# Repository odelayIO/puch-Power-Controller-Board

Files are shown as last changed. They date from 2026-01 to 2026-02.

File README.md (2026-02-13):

# puch-Power-Controller-Board

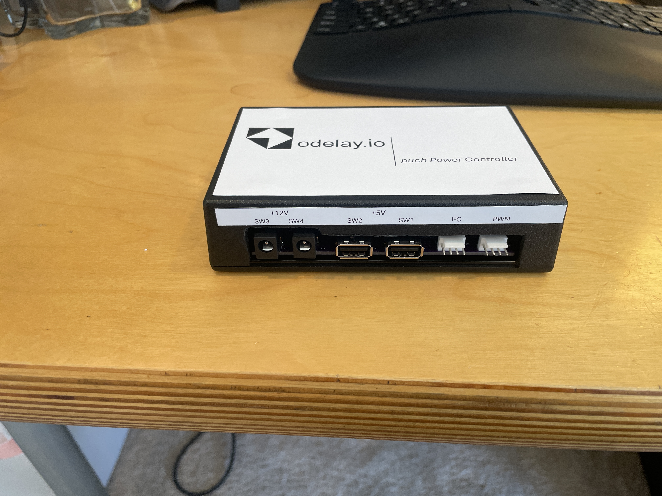
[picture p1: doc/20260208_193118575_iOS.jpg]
20260208_193118575_iOS


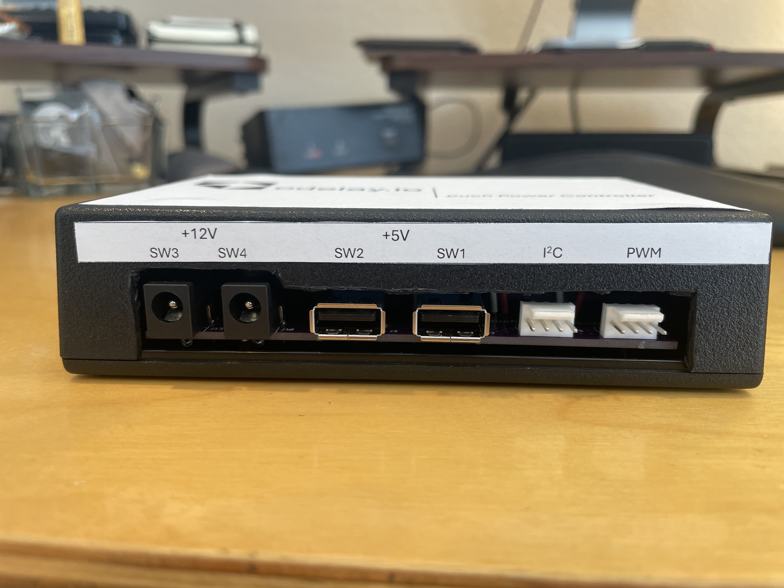
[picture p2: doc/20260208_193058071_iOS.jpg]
20260208_193058071_iOS


## Overview

KiCAD 9.0 board design for the puch Power Controller Board.  This boad has the following features:

- Create a custom PCB to remotely control the power input for KR260, PYNQ-Z1, and both Pluto SDRs
- Single 12VDC power supply will source power to all 4 devices
- Add clean external power to both Pluto SDRs (minimum ripple noise)
- Add PWM fan controlled by the ESP32 micro-controller to adjust fan speed
- Integration to Home Assistant via MQTT device
- Utilize already existing parts in my stock :)

### High-Level Block Diagram

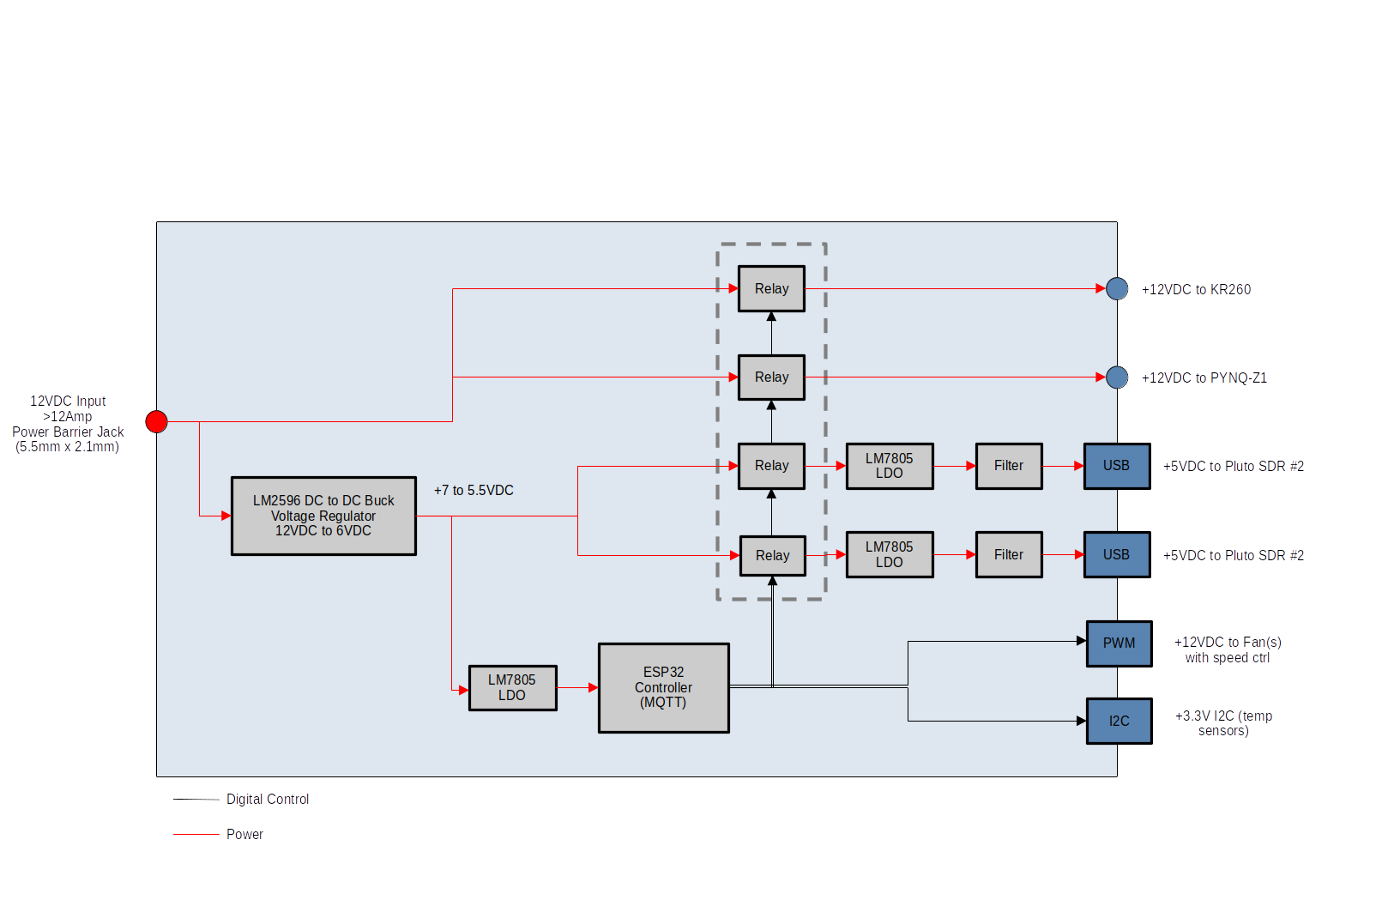
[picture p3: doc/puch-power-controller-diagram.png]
puch-power-controller-diagram


### KiCAD Images

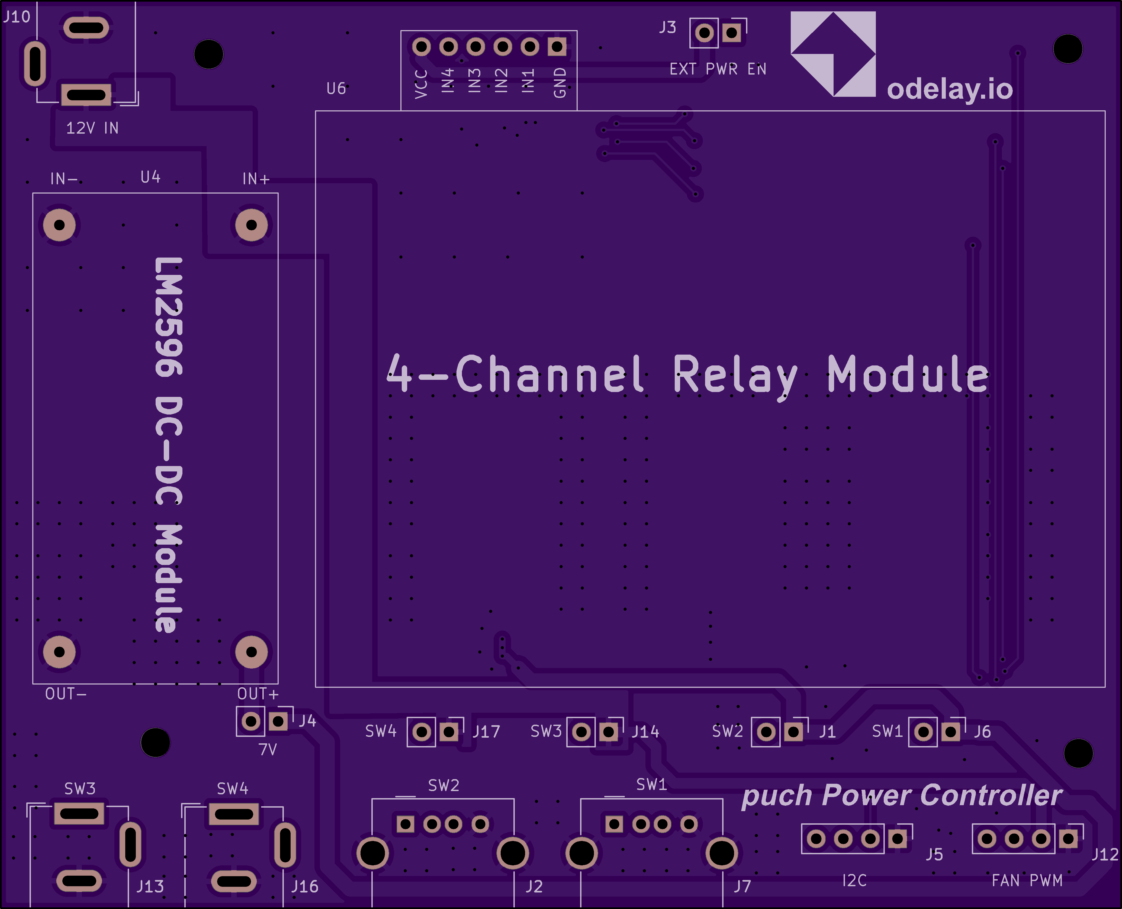
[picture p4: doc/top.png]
top


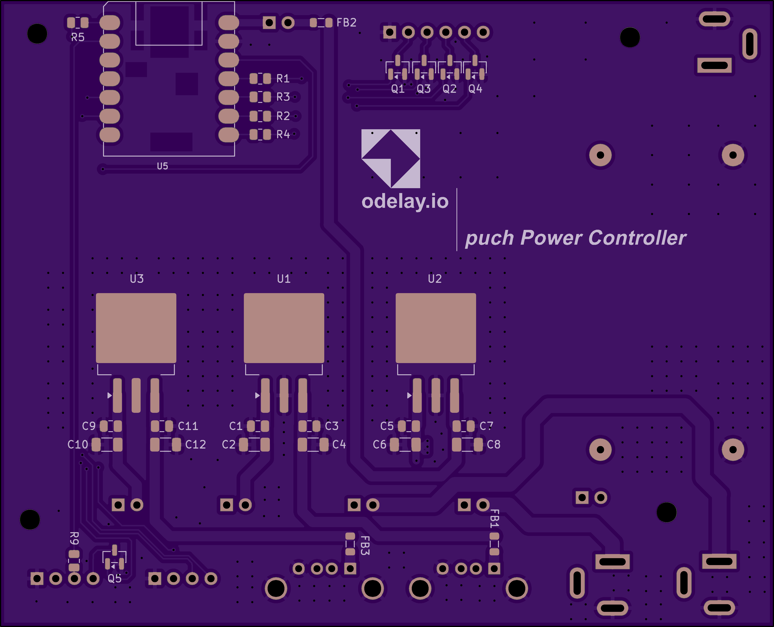
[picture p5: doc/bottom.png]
bottom


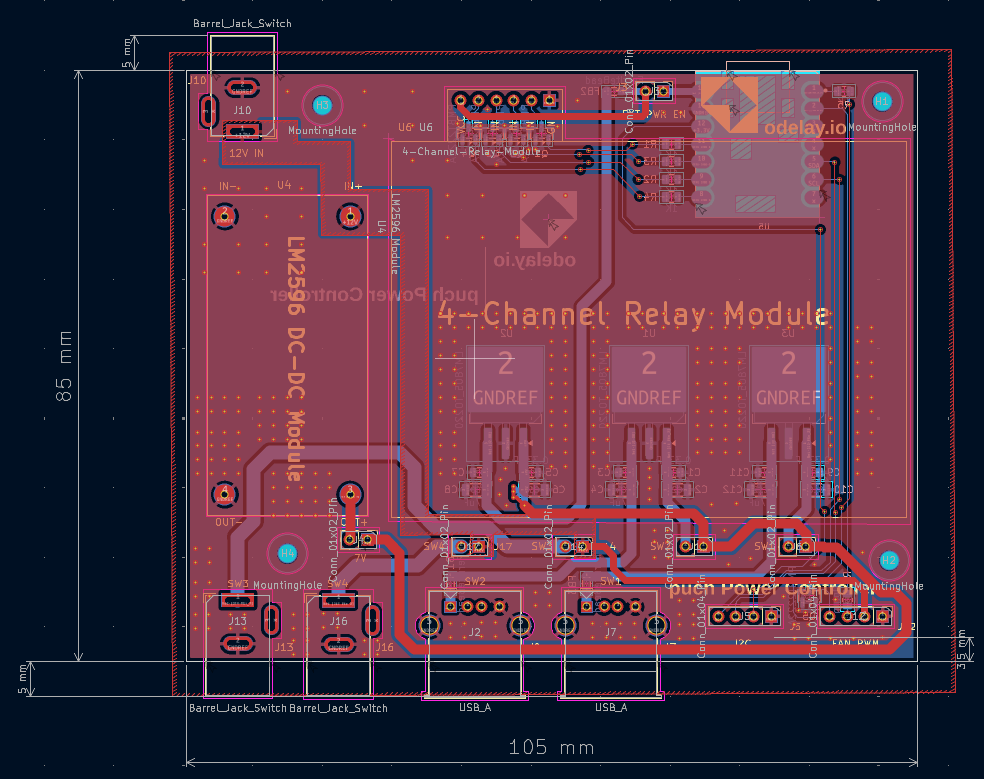
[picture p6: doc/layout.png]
layout


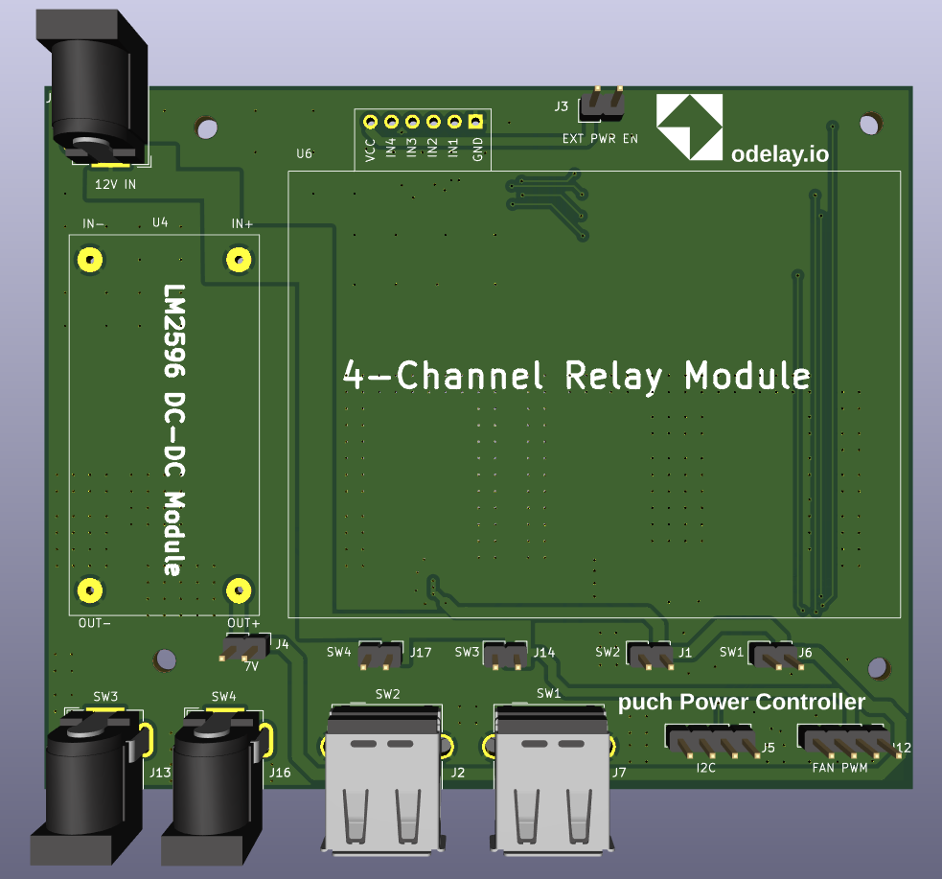
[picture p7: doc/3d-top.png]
3d-top


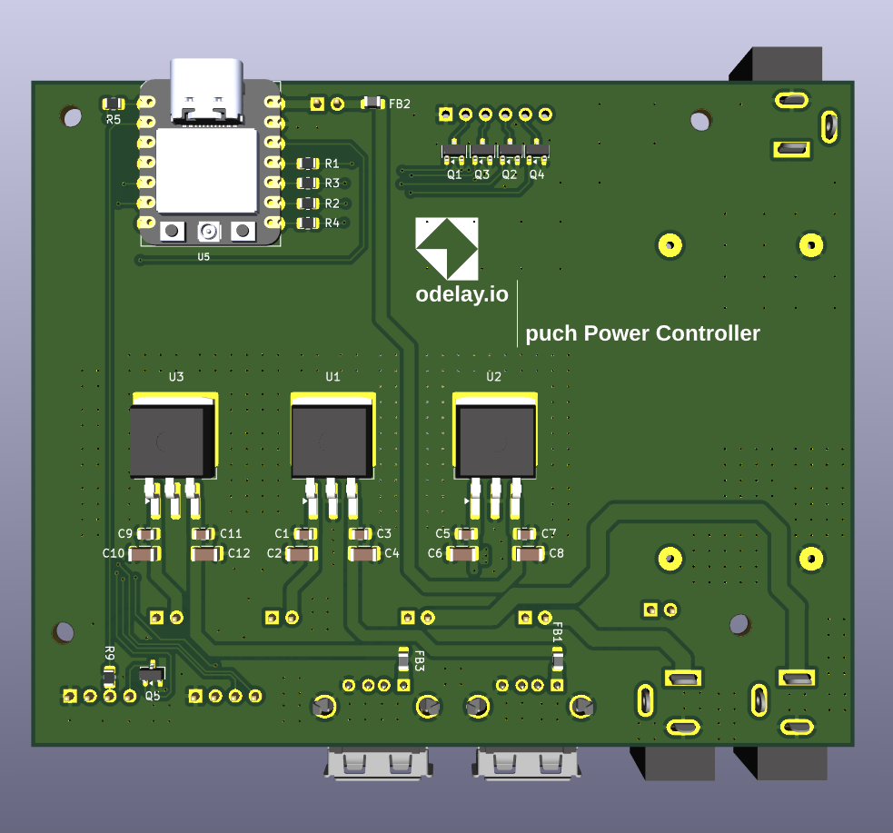
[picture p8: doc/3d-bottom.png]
3d-bottom


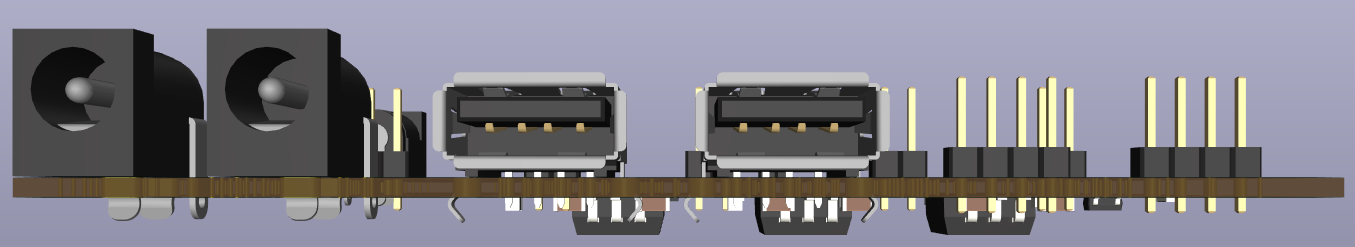
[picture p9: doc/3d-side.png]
3d-side


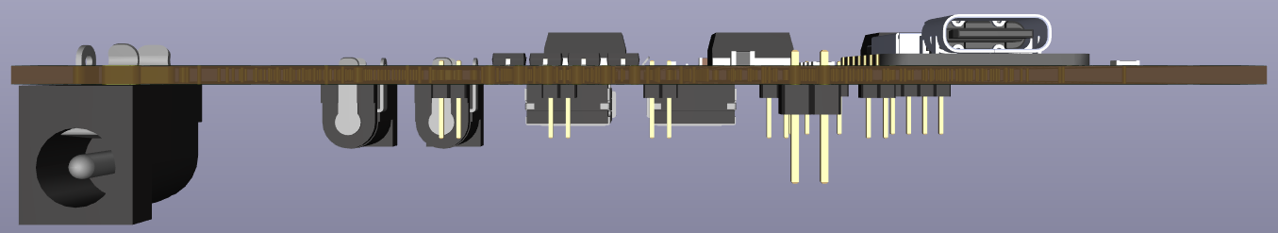
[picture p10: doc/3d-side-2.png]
3d-side-2


## KiCAD Design

The design was created using KiCAD 9.0.  The following provides a brief description of the files in the repository and the BOM.

| Document | Description |
| --- | --- |
| puch-Power-Controller-Board_Gerber-Output.zip | The Gerber files for fabrication of the PCB board.  This board was fabricated at [OSH Park](https://oshpark.com/). |
| puch-power-controller-SCH.pdf | PDF copy of the schematic |
| *.kicad_pcb, *.kicad_prl, *.kicad_sch, *.kicad_pro | The KiCAD 9.0 design files |
| /lib/odelay and /lib/xiao | KiCAD 9.0 Library for the components |

### Bill Of Materials

| Reference | Qty  | Value | Mouser Part # |
| --- | ---- | --- | --- |
| C1,C5,C9 | 3 | 0.33uF | 963-EMK212B7334KG-T  |
| C2,C6,C10 | 3 | 22uF | 581-TAJA226K006R |
| C3,C7,C11 | 3 | 0.1uF | 963-LMK212SD104KG-T  |
| C4,C8,C12 | 3 | 47uF | 581-TAJA476K006SNJV  |
| FB1,FB2,FB3 | 3 | FerriteBead | 81-BLM21SP181SN1D |
| H1,H2,H3,H4 | 4 | MountingHole | |
| J1,J3,J4,J6,J14,J17 | 6 | Conn_01x02_Pin | |
| J2,J7 | 2 | USB_A | 538-67643-0910 |
| J5,J12 | 2 | Conn_01x04_Pin | 538-22-05-3041 |
| J10,J13,J16 | 3 | Barrel_Jack_Switch | 640-DCJ250-10-A-K1-K |
| Q1,Q2,Q3,Q4,Q5 | 5 | PMBT2222A | 750-MMBT2222A-HF |
| R1,R2,R3,R4,R5 | 5 | 1K | |
| R9 | 1 | 0ohm | |
| U1,U2,U3 | 3 | LM7805_TO220 | 595-LM7805SX/NOPB |
| U4 | 1 | LM2596_Module | |
| U5 | 1 | MOUDLE-SEEEDUINO-XIAO-ESP32C3 | |
| U6 | 1 | 4-Channel-Relay-Module | |

## Assembly

Re-flowed the LM7805 voltage regulators to PCB due to the large copper heat sink.

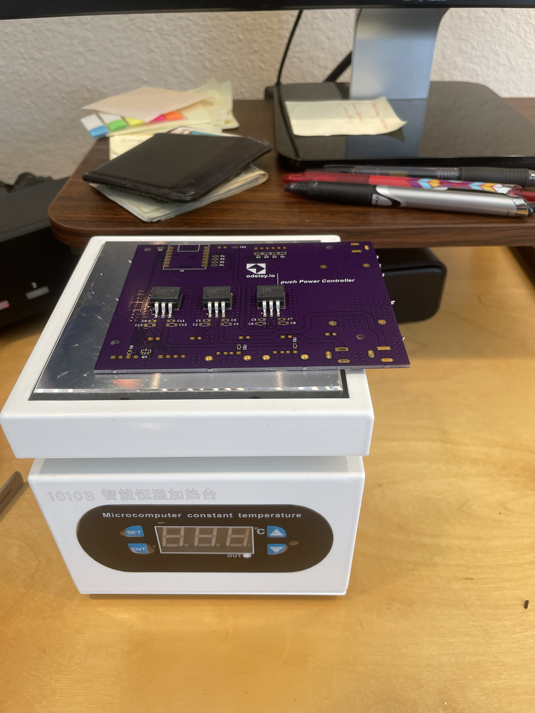
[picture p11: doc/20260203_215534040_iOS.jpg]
20260203_215534040_iOS


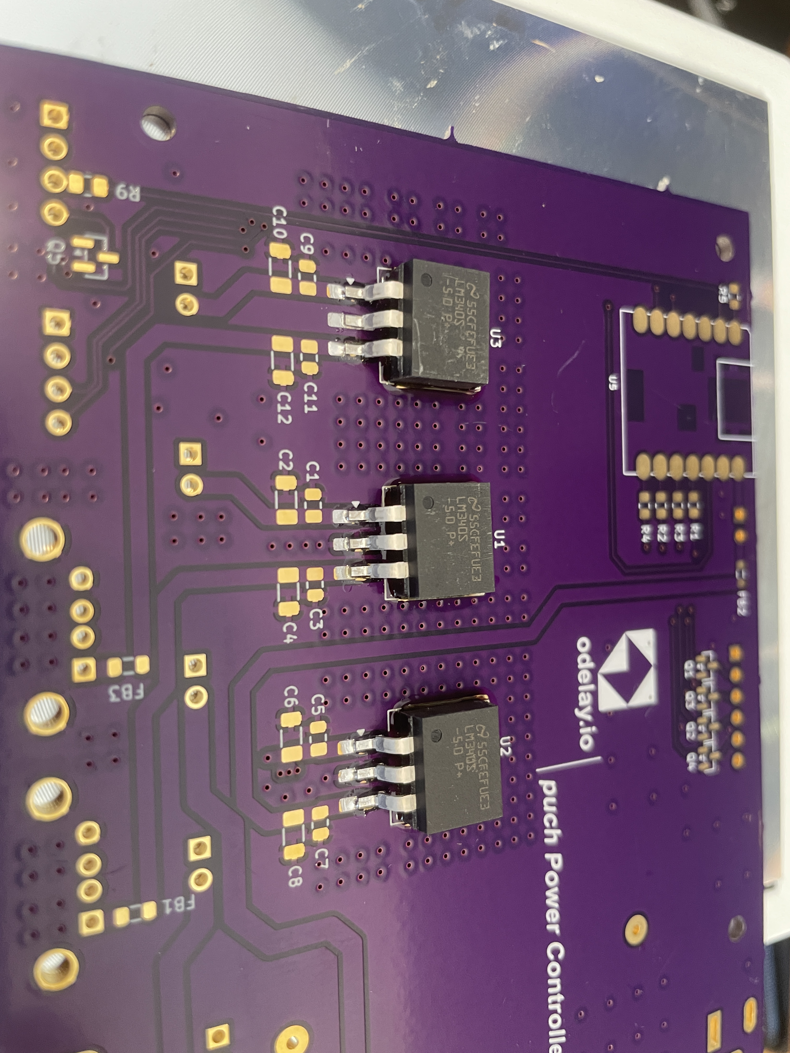
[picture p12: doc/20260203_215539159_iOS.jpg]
20260203_215539159_iOS


20260206_191316677_iOS

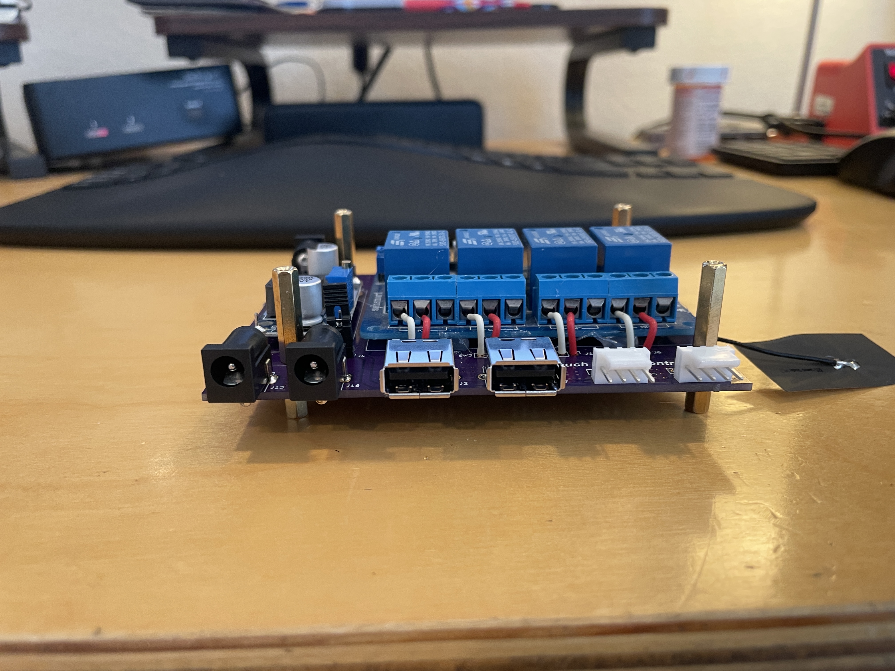
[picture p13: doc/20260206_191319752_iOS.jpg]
20260206_191319752_iOS


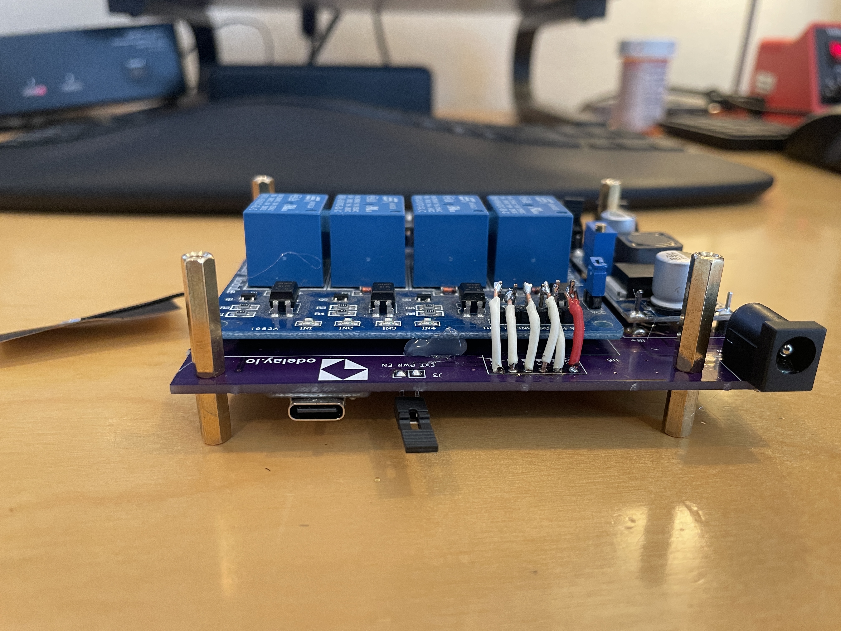
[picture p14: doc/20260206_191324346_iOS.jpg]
20260206_191324346_iOS


## Verification

PWM verification using oscilloscope

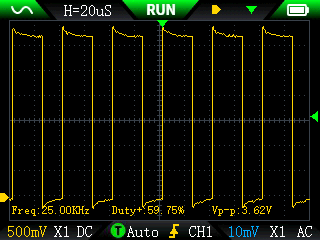
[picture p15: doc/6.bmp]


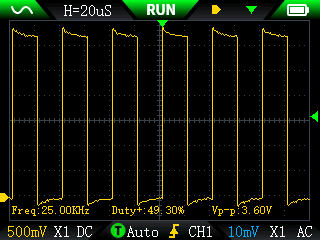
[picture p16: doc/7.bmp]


## XIAO ESP32-C3 Firmware

The firmware is in the Home Assistant Devices repository: 

https://github.com/odelayIO/Home-Assistant-Devices/tree/main/HA_MQTT_puch_rack_controller

### Home Assistant Integration:

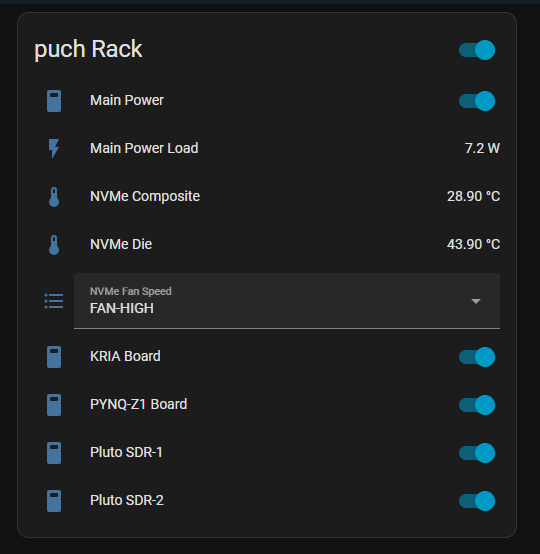
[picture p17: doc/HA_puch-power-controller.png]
HA_puch-power-controller


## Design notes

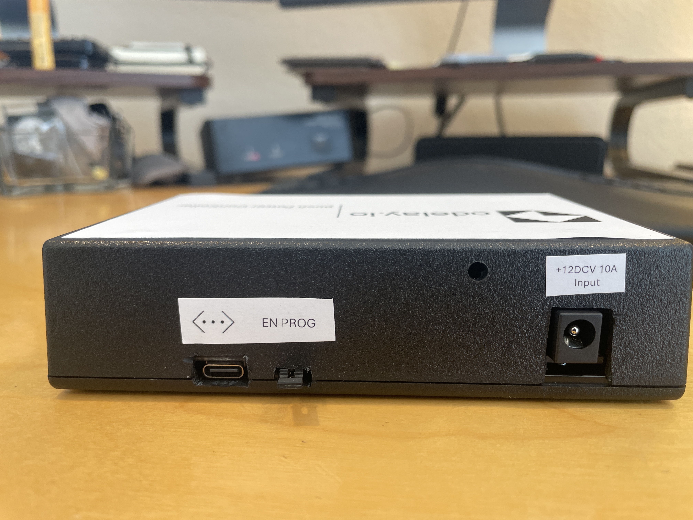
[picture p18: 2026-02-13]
doc/20260208_193124782_iOS.jpg

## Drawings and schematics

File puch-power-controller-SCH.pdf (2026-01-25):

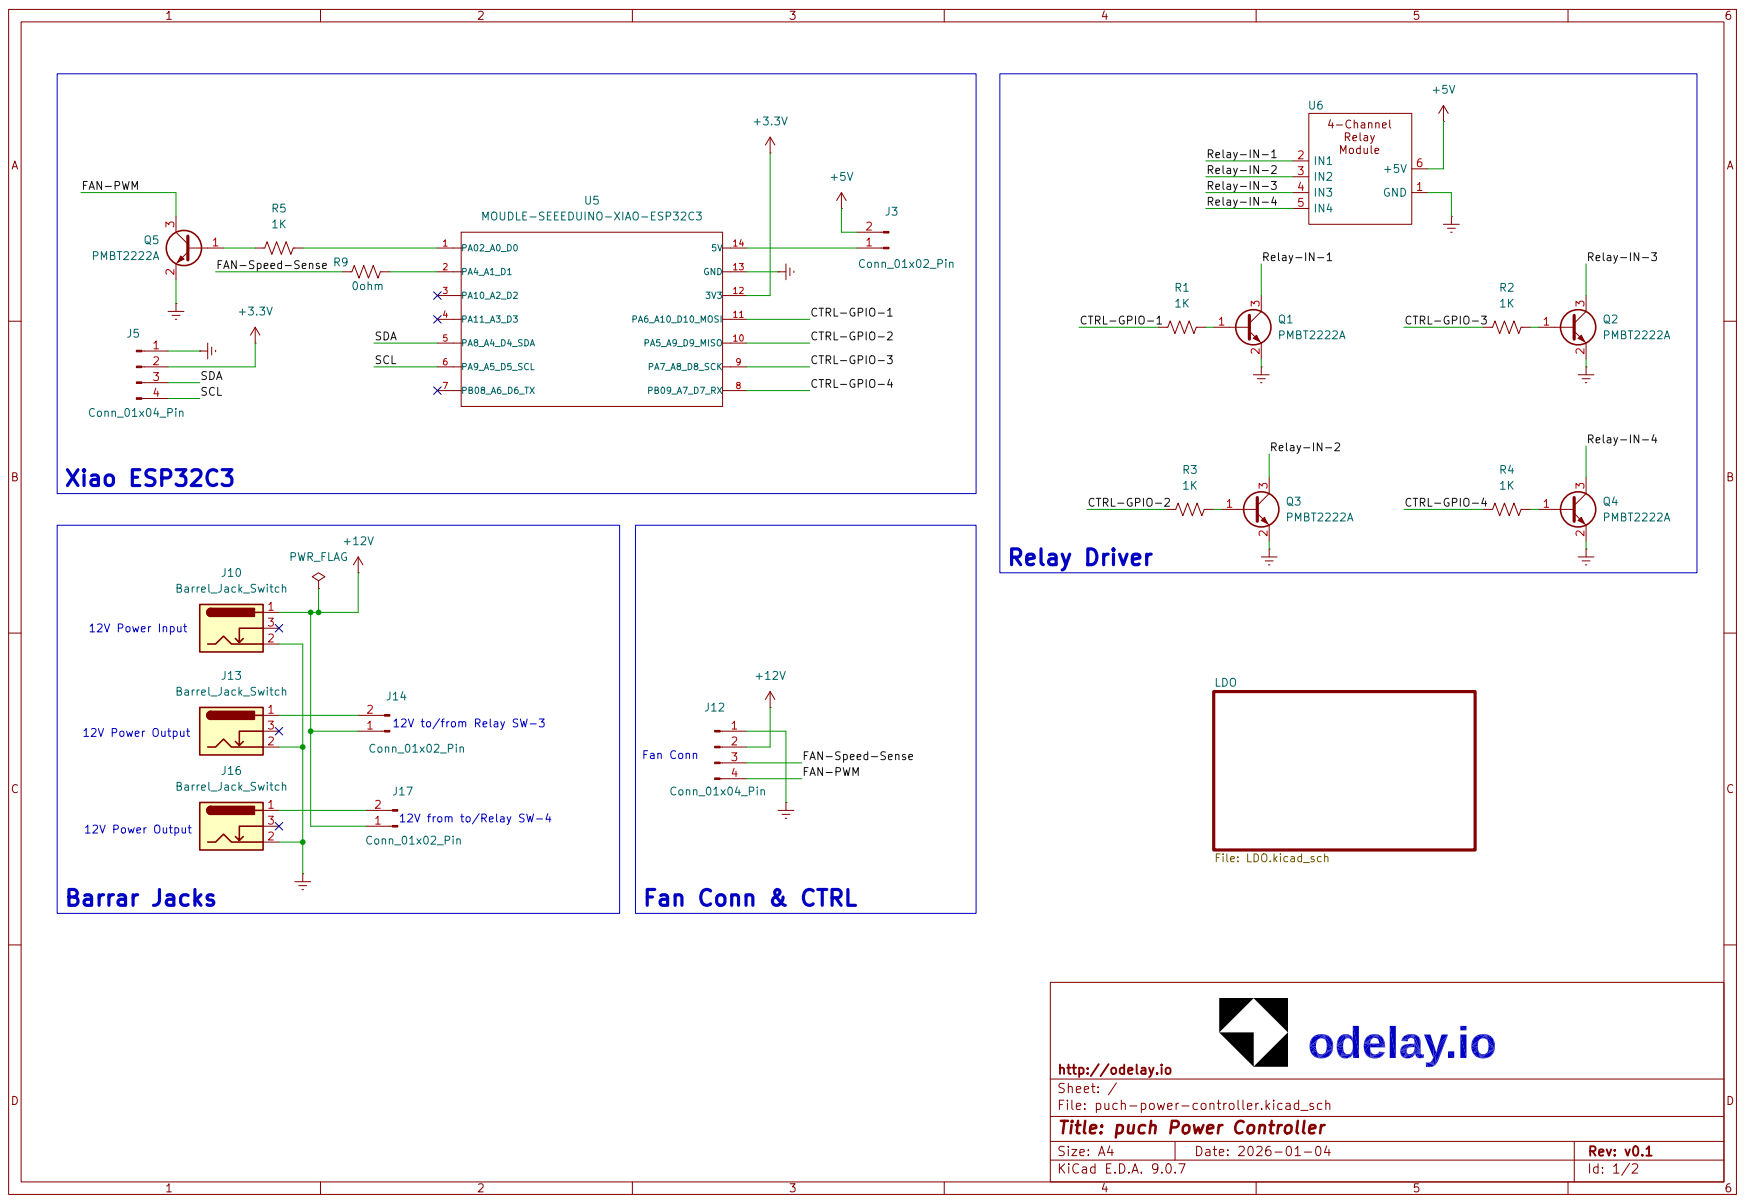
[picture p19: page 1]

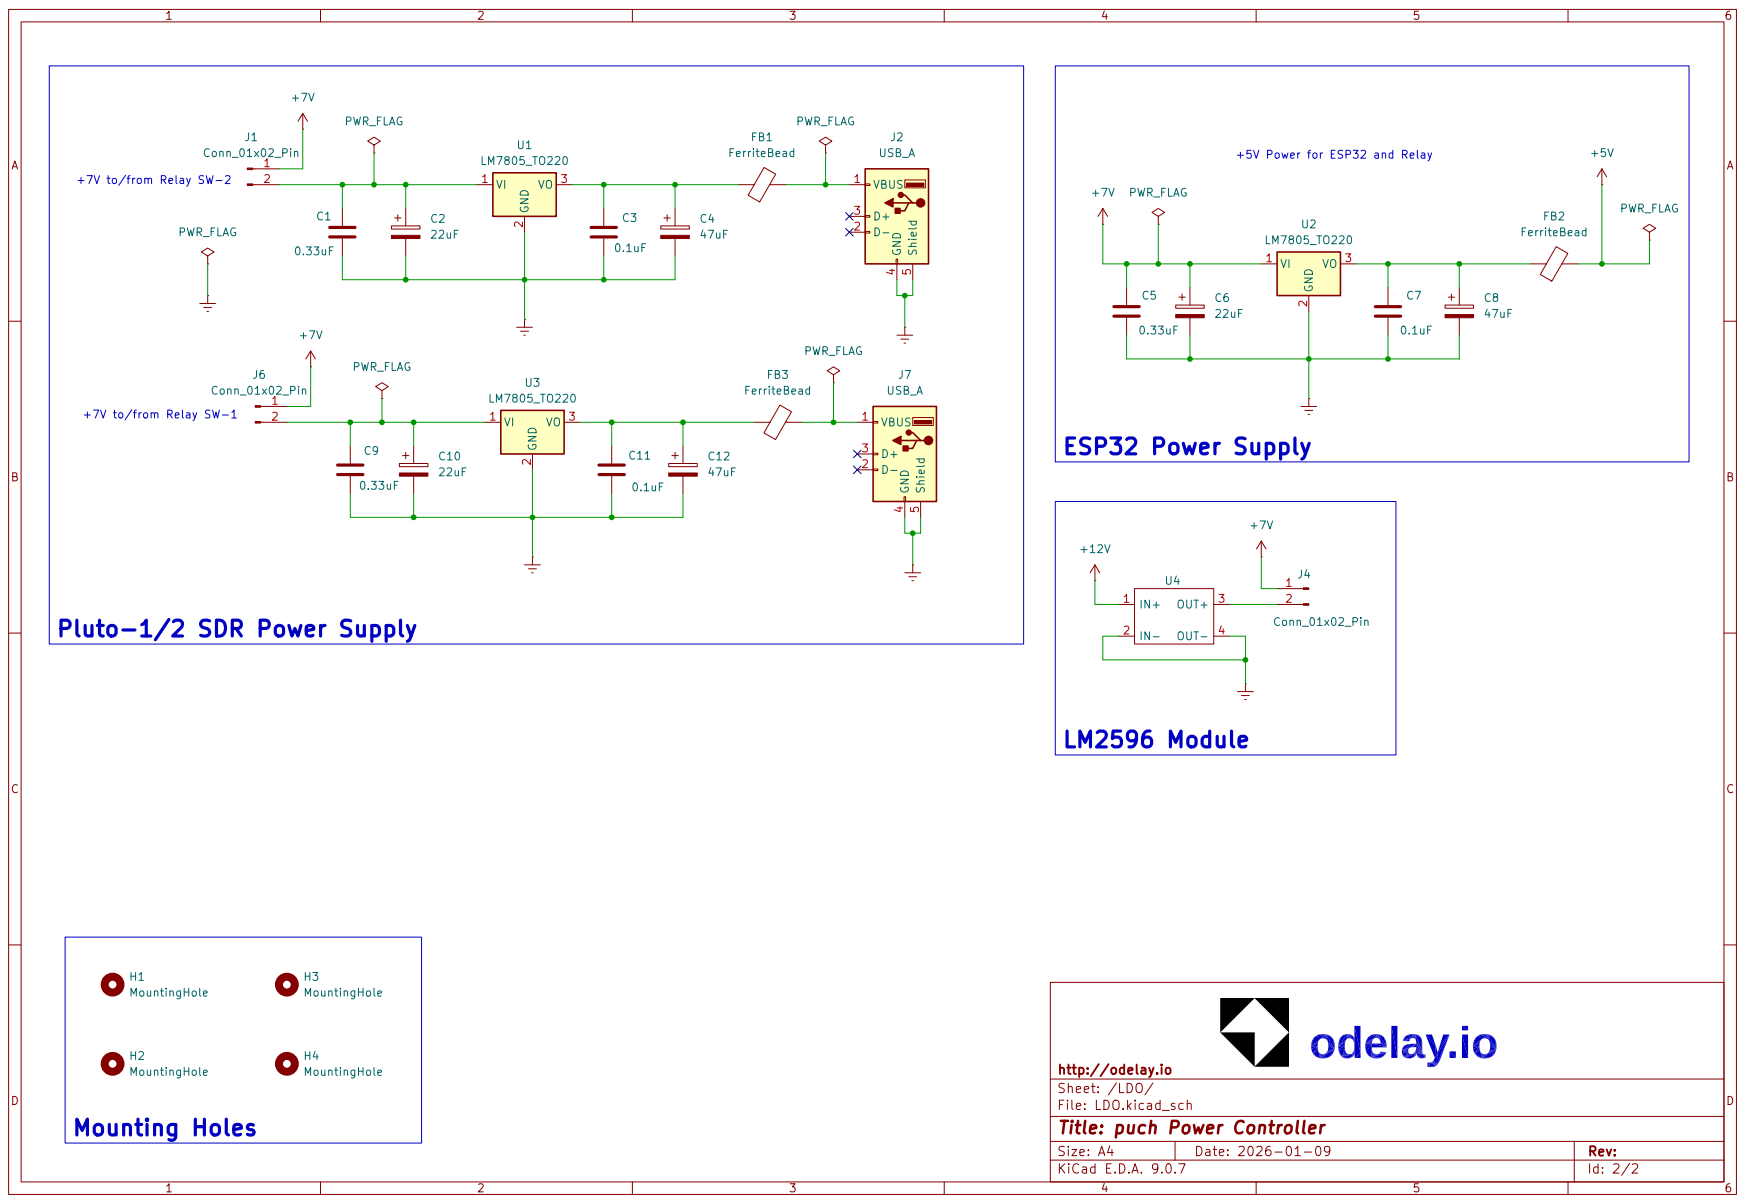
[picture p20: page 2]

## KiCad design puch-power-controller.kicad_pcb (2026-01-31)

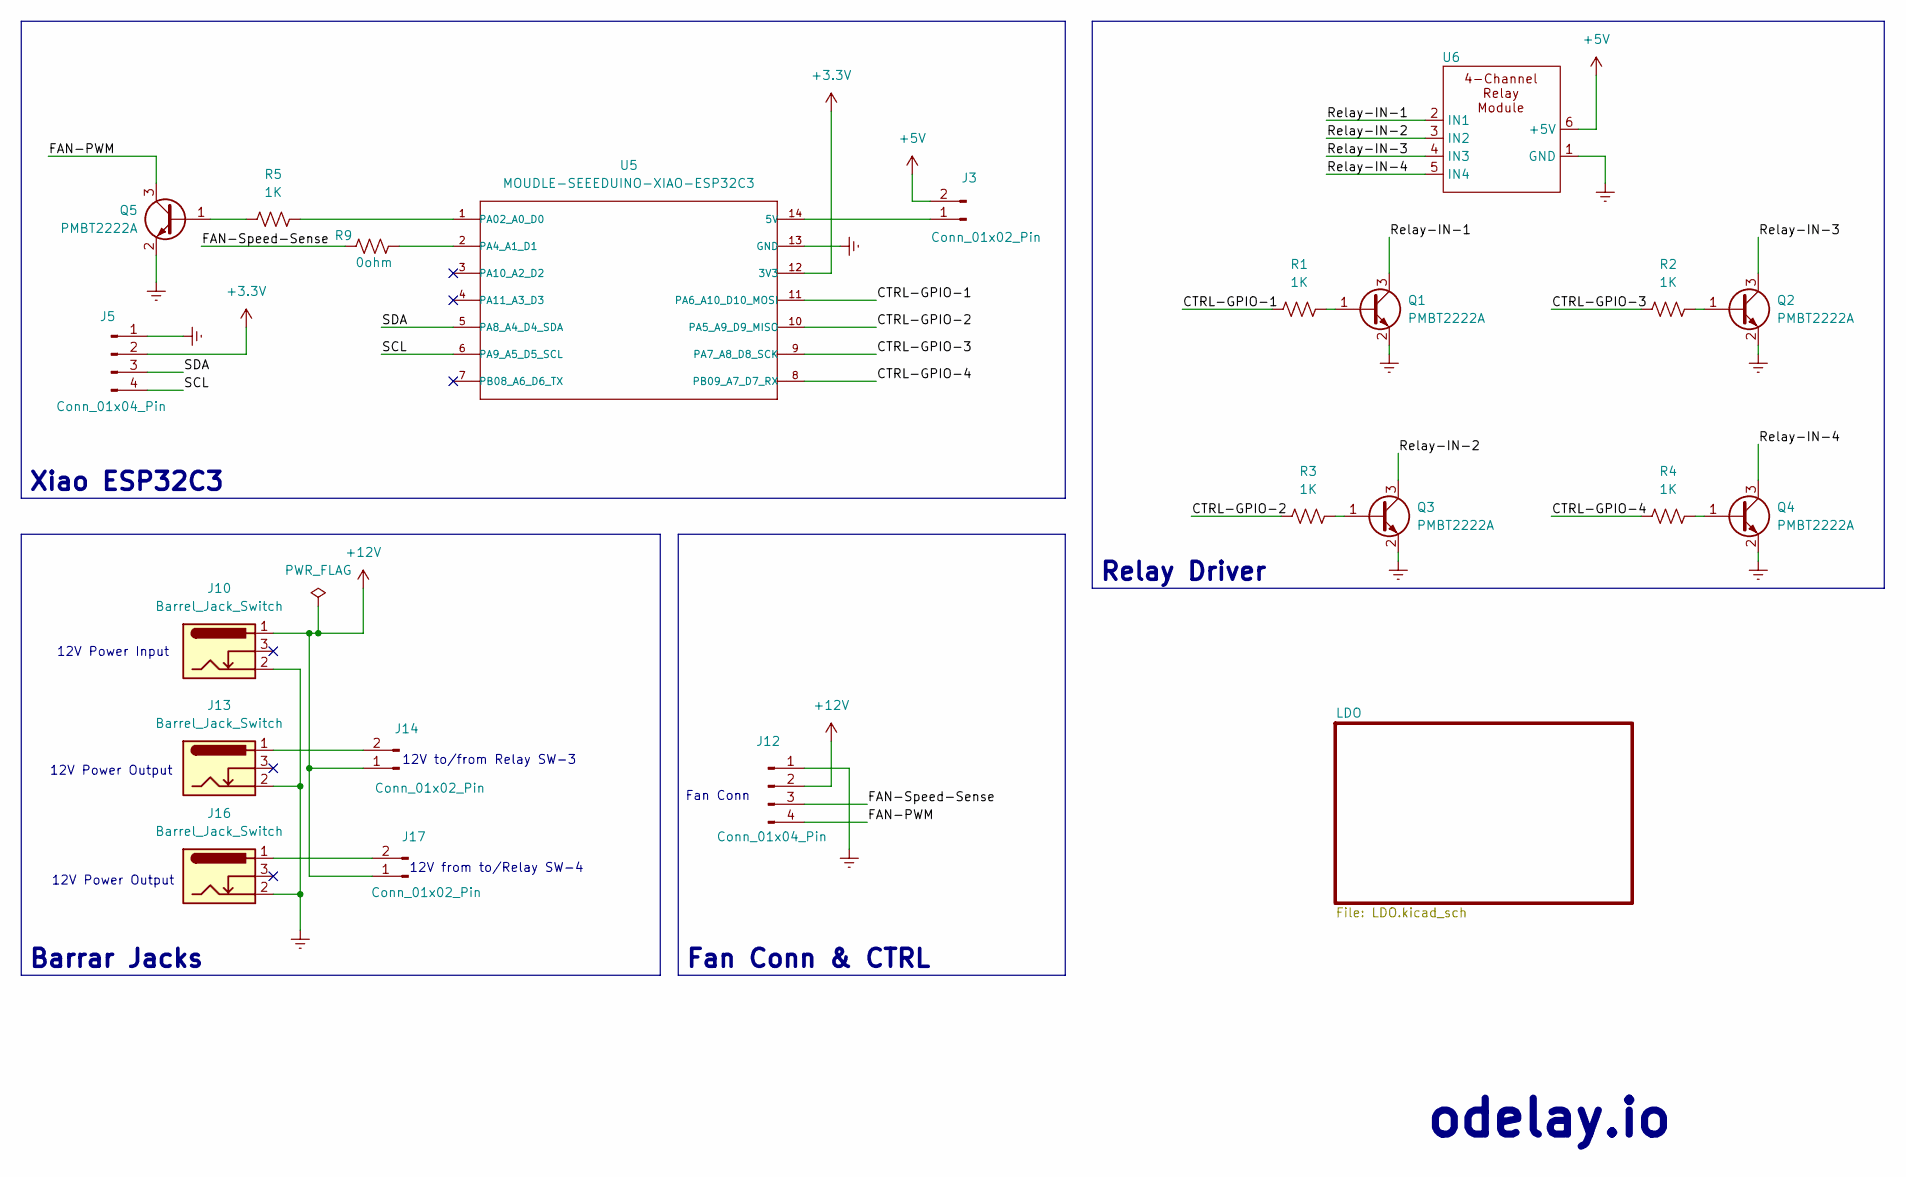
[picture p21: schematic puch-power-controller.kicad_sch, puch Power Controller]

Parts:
J3, J14, J17: Conn_01x02_Pin; PinHeader_1x02_P2.54mm_Vertical
J5, J12: Conn_01x04_Pin; PinHeader_1x04_P2.54mm_Vertical; Mouser Part # 538-22-05-3041
J10, J13, J16: Barrel_Jack_Switch; BarrelJack_GCT_DCJ200-10-A_Horizontal; Mouser Part # 640-DCJ250-10-A-K1-K
Q1, Q2, Q3, Q4, Q5: PMBT2222A; SOT-23; Mouser Part # 750-MMBT2222A-HF
R1, R2, R3, R4, R5: 1K; R_0805_2012Metric
R9: 0ohm; R_0805_2012Metric
U5: MOUDLE-SEEEDUINO-XIAO-ESP32C3; MOUDLE14P-SMD-2.54-21X17.8MM
U6: 4-Channel-Relay-Module; 4-Channel-Relay

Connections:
+3.3V: J5.2, U5.12 (3V3)
+5V: J3.2, U6.6 (+5V); also elsewhere on the board
+12V: J10.1, J12.2, J14.1, J17.1; also elsewhere on the board
/CTRL-GPIO-1: R1.1, U5.11 (PA6_A10_D10_MOSI)
/CTRL-GPIO-2: R3.1, U5.10 (PA5_A9_D9_MISO)
/CTRL-GPIO-3: R2.1, U5.9 (PA7_A8_D8_SCK)
/CTRL-GPIO-4: R4.1, U5.8 (PB09_A7_D7_RX)
/FAN-PWM: J12.4, Q5.3 (C)
/FAN-Speed-Sense: J12.3, R9.1
/Relay-IN-1: Q1.3 (C), U6.2 (IN1)
/Relay-IN-2: Q3.3 (C), U6.3 (IN2)
/Relay-IN-3: Q2.3 (C), U6.4 (IN3)
/Relay-IN-4: Q4.3 (C), U6.5 (IN4)
/SCL: J5.4, U5.6 (PA9_A5_D5_SCL)
/SDA: J5.3, U5.5 (PA8_A4_D4_SDA)
GNDREF: J5.1, J10.2, J12.1, J13.2, J16.2, Q1.2 (E), Q2.2 (E), Q3.2 (E), Q4.2 (E), Q5.2 (E), U5.13 (GND), U6.1 (GND); also elsewhere on the board
unnamed: J3.1, U5.14 (5V)
unnamed: J13.1, J14.2
unnamed: J16.1, J17.2
unnamed: Q1.1 (B), R1.2
unnamed: Q2.1 (B), R2.2
unnamed: Q3.1 (B), R3.2
unnamed: Q4.1 (B), R4.2
unnamed: Q5.1 (B), R5.1
unnamed: R5.2, U5.1 (PA02_A0_D0)
unnamed: R9.2, U5.2 (PA4_A1_D1)

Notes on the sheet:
12V Power Input
12V from to/Relay SW-4
odelay.io
12V Power Output
12V to/from Relay SW-3
Fan Conn
Xiao ESP32C3
Barrar Jacks
Relay Driver
Fan Conn & CTRL

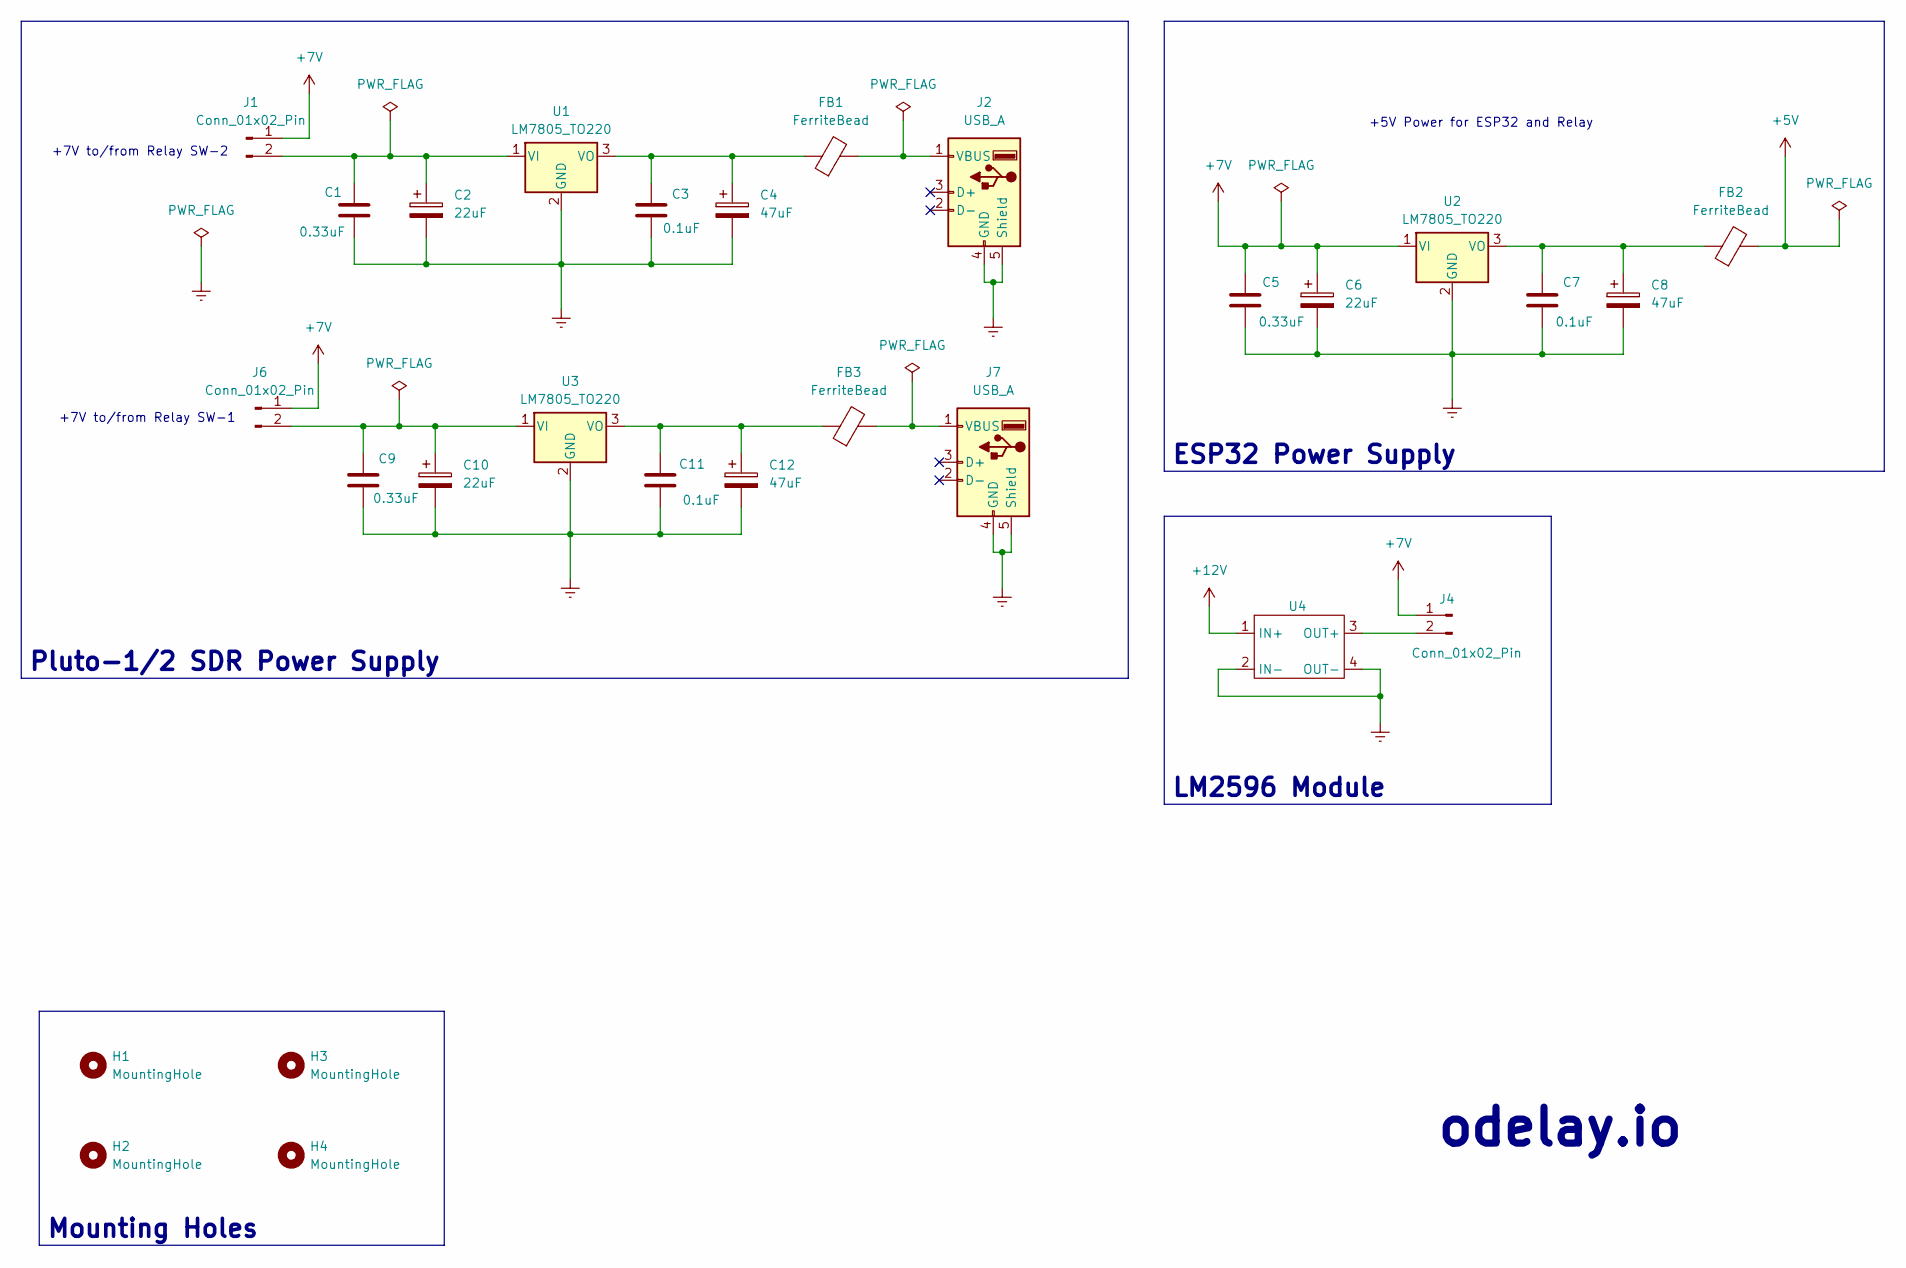
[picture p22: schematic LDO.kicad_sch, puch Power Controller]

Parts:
C1, C5, C9: 0.33uF; C_0805_2012Metric; Mouser Part # 963-EMK212B7334KG-T
C2, C6, C10: 22uF; C_1206_3216Metric; Mouser Part # 581-TAJA226K006R
C3, C7, C11: 0.1uF; C_0805_2012Metric; Mouser Part # 963-LMK212SD104KG-T
C4, C8, C12: 47uF; C_1206_3216Metric; Mouser Part # 581-TAJA476K006SNJV
FB1, FB2, FB3: FerriteBead; L_0805_2012Metric; Mouser Part # 81-BLM21SP181SN1D
H1, H2, H3, H4: MountingHole; MountingHole_2.7mm_M2.5
J1, J4, J6: Conn_01x02_Pin; PinHeader_1x02_P2.54mm_Vertical
J2, J7: USB_A; USB_A_Molex_67643_Horizontal; Mouser Part # 538-67643-0910
U1, U2, U3: LM7805_TO220; TO-263-3_TabPin2; Mouser Part # 595-LM7805SX/NOPB
U4: LM2596_Module

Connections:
+5V: FB2.2; also elsewhere on the board
+7V: C5.1, C6.1, J1.1, J4.1, J6.1, U2.1 (VI)
+12V: U4.1 (IN+); also elsewhere on the board
GNDREF: C1.2, C2.2, C3.2, C4.2, C5.2, C6.2, C7.2, C8.2, C9.2, C10.2, C11.2, C12.2, J2.4 (GND), J2.5 (Shield), J7.4 (GND), J7.5 (Shield), U1.2 (GND), U2.2 (GND), U3.2 (GND), U4.2 (IN-), U4.4 (OUT-); also elsewhere on the board
unnamed: C1.1, C2.1, J1.2, U1.1 (VI)
unnamed: FB1.2, J2.1 (VBUS)
unnamed: J4.2, U4.3 (OUT+)
unnamed: C9.1, C10.1, J6.2, U3.1 (VI)
unnamed: FB3.2, J7.1 (VBUS)
unnamed: C3.1, C4.1, FB1.1, U1.3 (VO)
unnamed: C7.1, C8.1, FB2.1, U2.3 (VO)
unnamed: C11.1, C12.1, FB3.1, U3.3 (VO)

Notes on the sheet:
+7V to/from Relay SW-1
+5V Power for ESP32 and Relay
odelay.io
+7V to/from Relay SW-2
LM2596 Module
ESP32 Power Supply
Pluto-1/2 SDR Power Supply
Mounting Holes

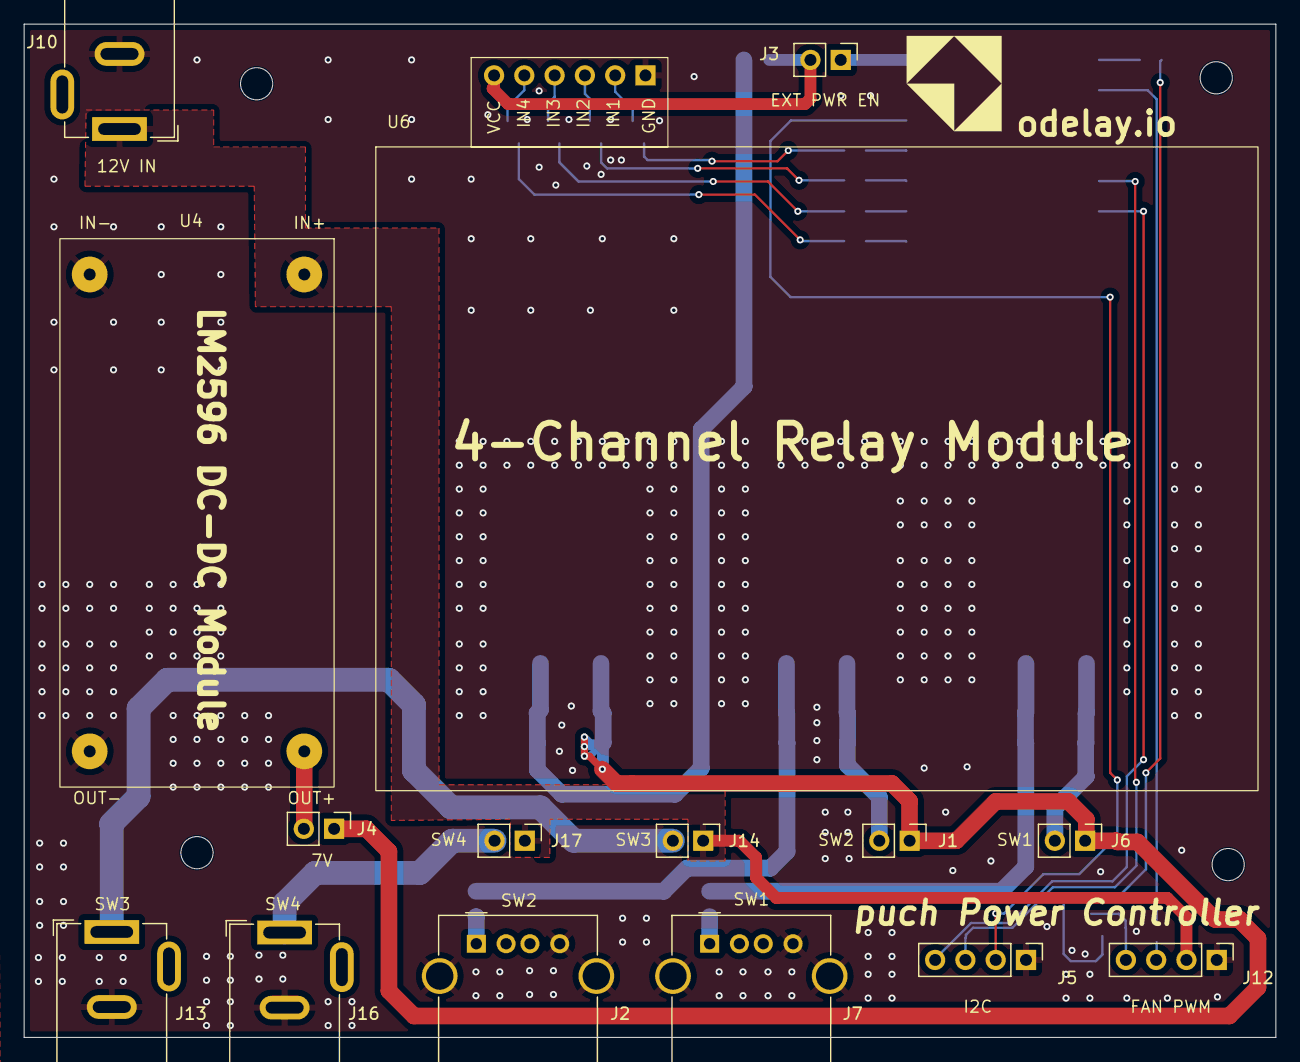
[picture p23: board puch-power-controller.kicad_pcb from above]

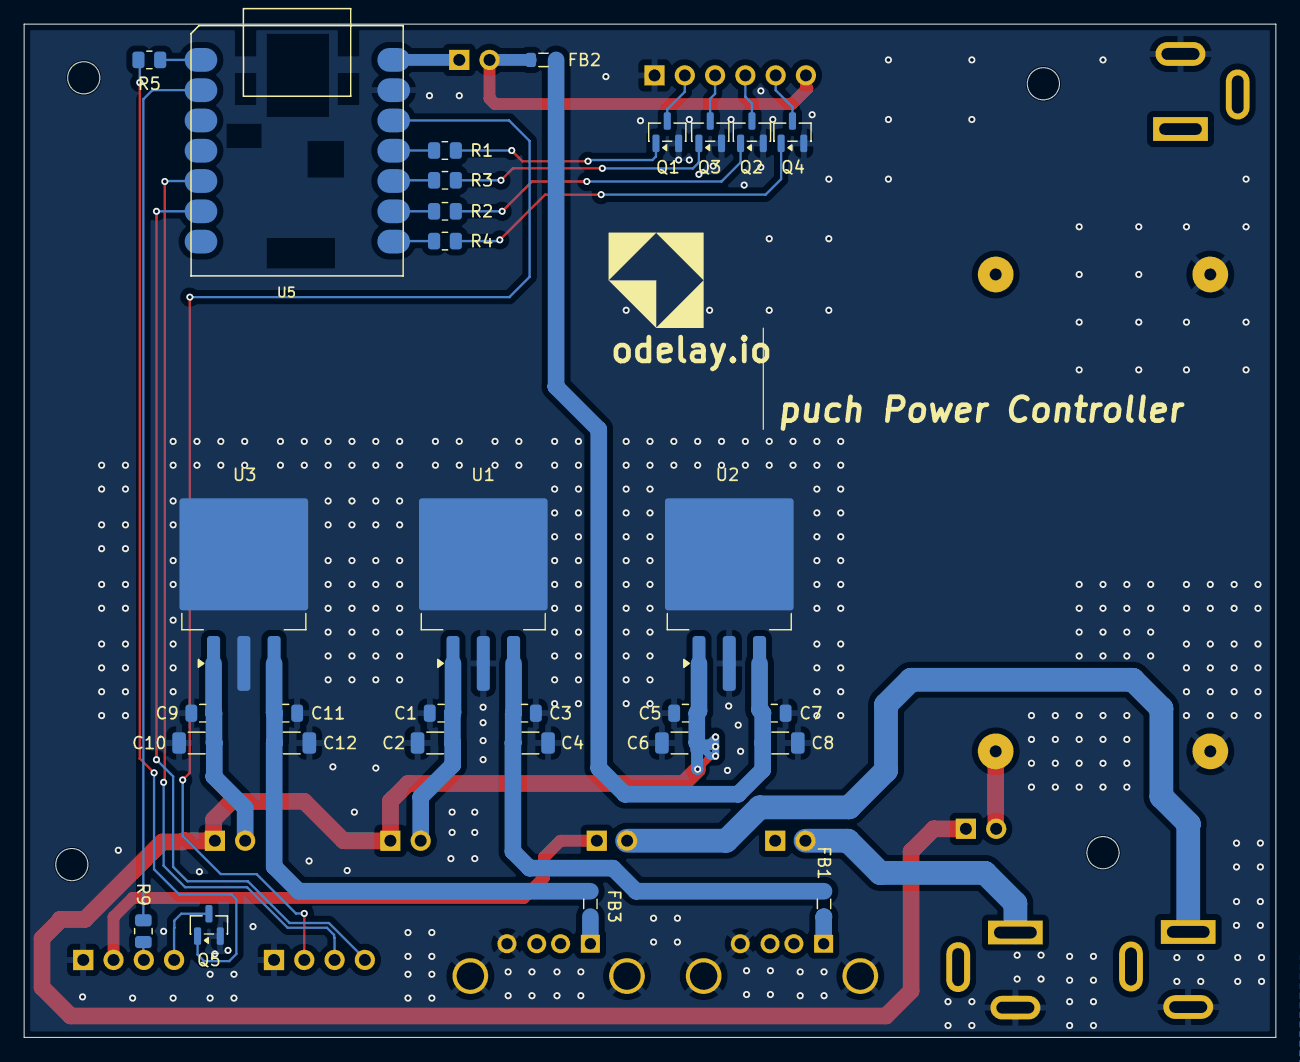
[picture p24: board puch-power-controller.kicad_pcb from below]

Board: 2 copper layers, 105.0 x 85.0 mm, 49 parts (30 on the bottom side), 35 nets.

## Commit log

2026-01-25 adding design files
    [LDO.kicad_sch, puch-power-controller.kicad_pcb, puch-power-controller.kicad_sch]
2026-01-31 added 3D model for XIAO
    [puch-power-controller.kicad_pcb]
